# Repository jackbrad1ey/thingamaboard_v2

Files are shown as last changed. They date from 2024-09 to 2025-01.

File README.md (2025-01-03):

# Thingamaboard V2
This is the second iteration of my custom mechanical keyboard, a low-profile board aiming to be reliable, portable and fully-featured.

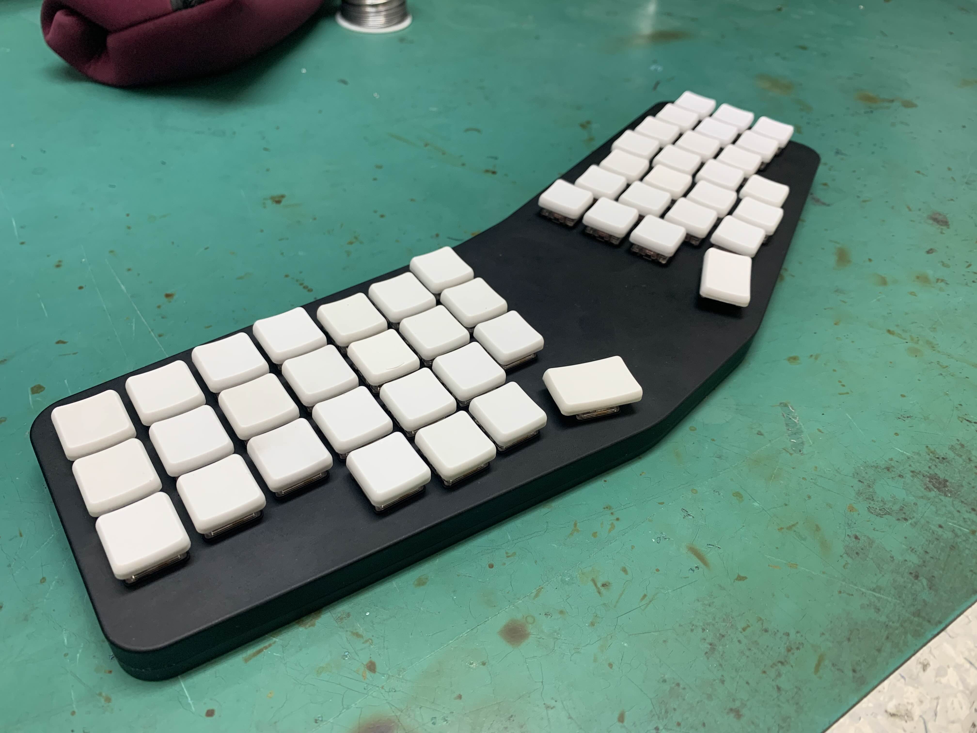
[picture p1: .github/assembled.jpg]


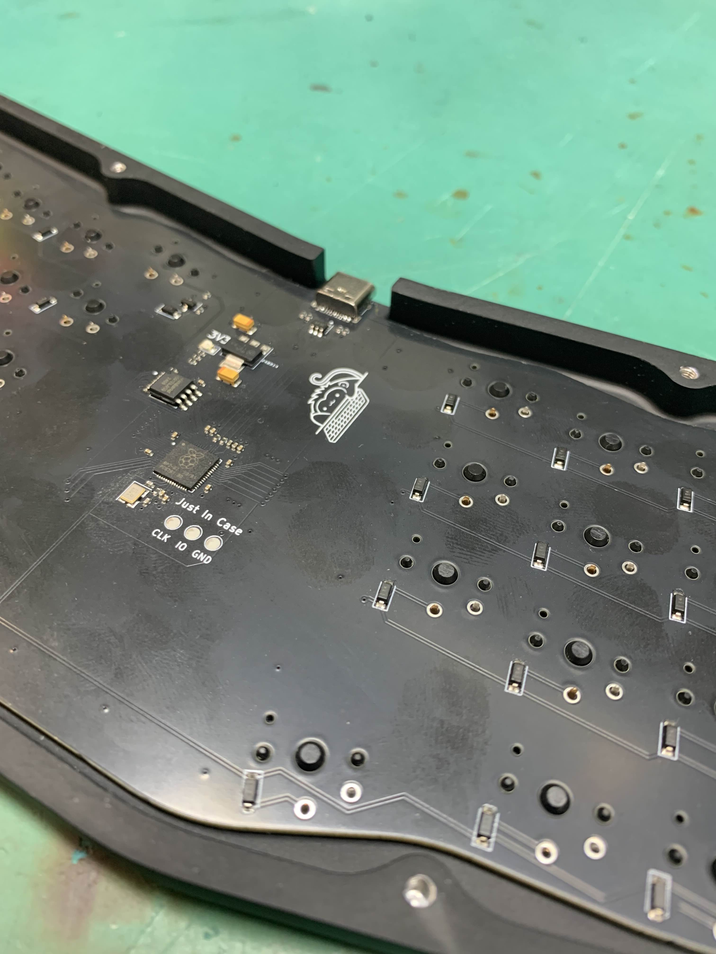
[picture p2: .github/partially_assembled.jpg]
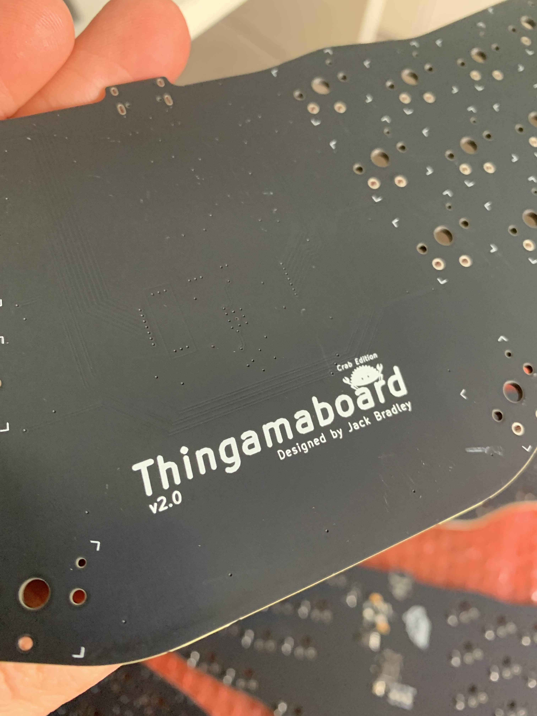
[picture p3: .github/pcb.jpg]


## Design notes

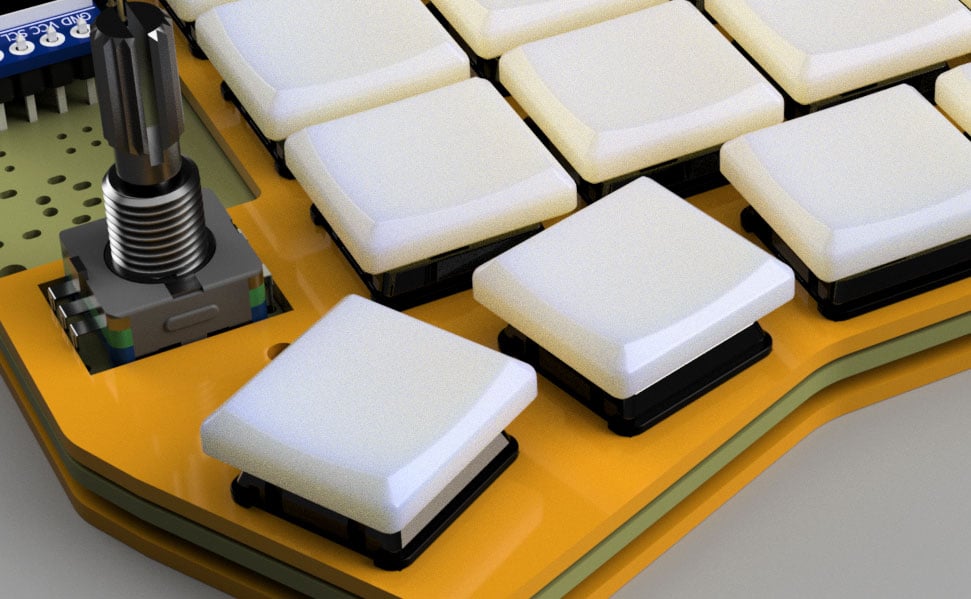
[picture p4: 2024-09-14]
CAD/keycaps/images/MBK-Keycap-render.jpg

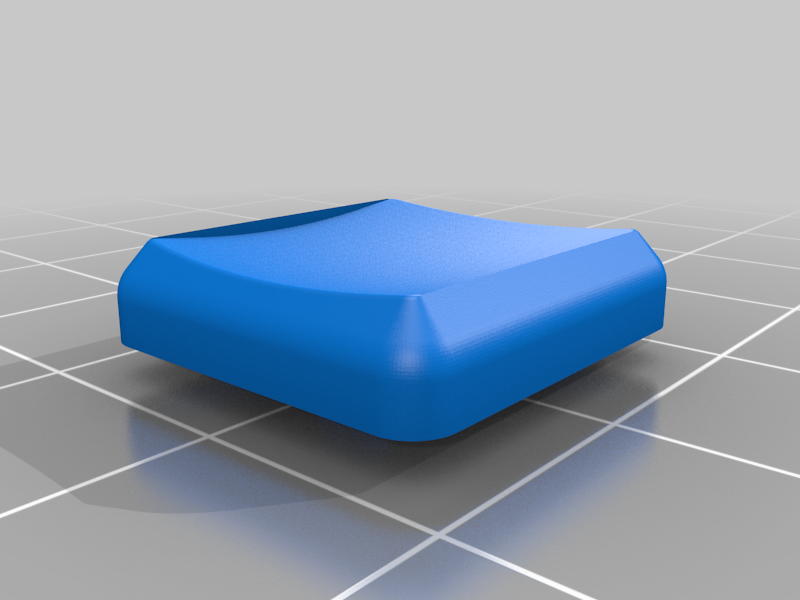
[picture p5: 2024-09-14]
CAD/keycaps/images/MBK_Keycap_-_1u_homing.png

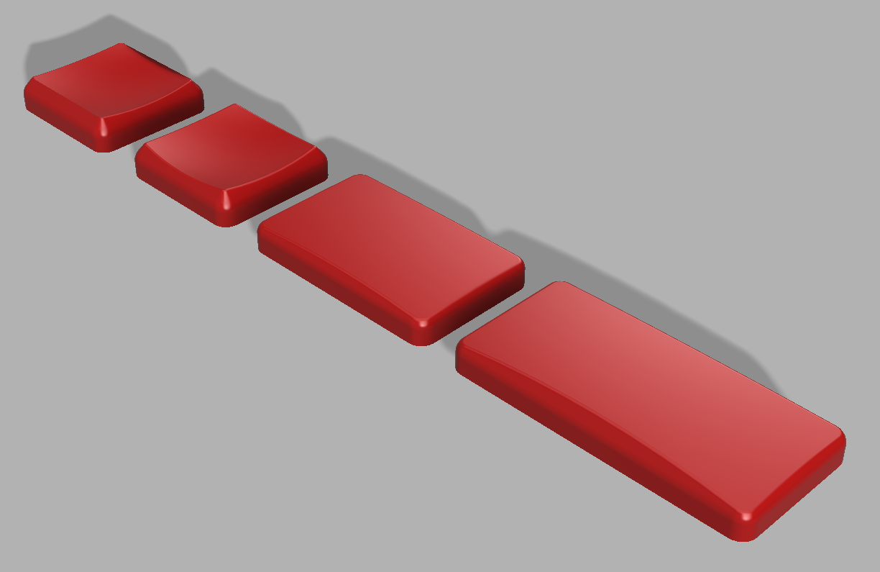
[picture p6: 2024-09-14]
CAD/keycaps/images/MBK_Keycap_family.png

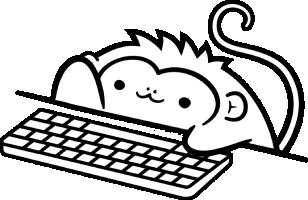
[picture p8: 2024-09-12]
pcb/graphics/monkei.png

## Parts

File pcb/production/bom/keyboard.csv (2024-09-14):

Comment | Designator | Footprint | JLCPCB Part #
10u Polarized capacitor | C1,C16 | C_1206_3216Metric | C7171
100n Unpolarized capacitor | C2,C5,C6,C7,C10,C11,C12,C13,C14,C15 | C_0402_1005Metric | C1525
15p Unpolarized capacitor | C3,C4 | C_0402_1005Metric | C1548
1u Unpolarized capacitor | C8,C9 | C_0402_1005Metric | C52923
NCD0805 Light emitting diode | D1 | LED_0805_2012Metric_Pad1.15x1.40mm_HandSolder | C84256
D_Small Diode, small symbol | D2,D3,D4,D5,D6,D7,D8,D9,D10,D11,D12,D13,D14,D15,D16,D17,D18,D19,D20,D21,D22,D23,D24,D25,D26,D27,D28,D29,D30,D31,D32,D33,D34,D35,D36,D37,D38,D39,D40,D41,D42,D43,D44,D45,D46,D47,D48,D49,D50,D51 | D_SOD-123 | C2099
USB_C_Receptacle_USB2.0 USB 2.0-only Type-C Receptacle connector | J1 | TYPE-C-31-M-12 | C165948
S8550 0.1A Ic, 30V Vce, PNP Transistor, SOT-23 | Q1 | SOT-23 | C105432
27 Resistor | R1,R2,R3,R12,R13 | R_0402_1005Metric | C25100
10k Resistor | R4,R5,R6,R7,R8,R10 | R_0402_1005Metric | C25744
1k Resistor | R9,R11 | R_0402_1005Metric | C11702
TestPoint test point | TP1,TP2,TP3 | TestPoint_Pad_D2.0mm
NCP1117-3.3_SOT223 1A Low drop-out regulator, Fixed Output 3.3V, SOT-223 | U1 | SOT-223-3_TabPin2 | C26537
USBLC6-2SC6 Very low capacitance ESD protection diode, 2 data-line, SOT-23-6 | U2 | SOT-23-6 | C2827654
W25Q128JVS 128Mb Serial Flash Memory, Standard/Dual/Quad SPI, SOIC-8 | U3 | SOIC-8_5.23x5.23mm_P1.27mm | C97521
RP2040 A microcontroller by Raspberry Pi | U4 | QFN-56-1EP_7x7mm_P0.4mm_EP3.2x3.2mm | C2040
ABM8-272_T3 Four pin crystal, GND on pins 2 and 4 | Y1 | Crystal_SMD_3225-4Pin_3.2x2.5mm | C20625731

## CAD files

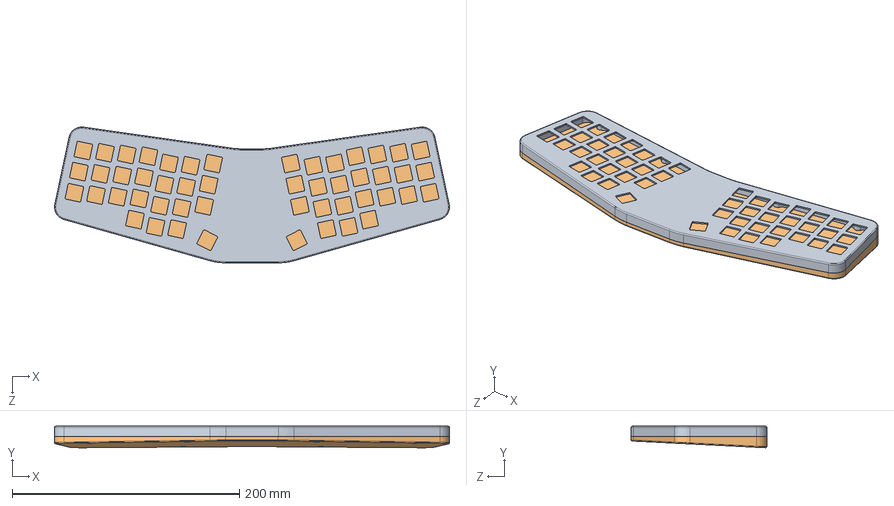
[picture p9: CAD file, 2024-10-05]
CAD/keyboard_assembly_2.SLDASM
347.3 x 18.9 x 119.5 mm
case_bottom_v2
top_case_v3

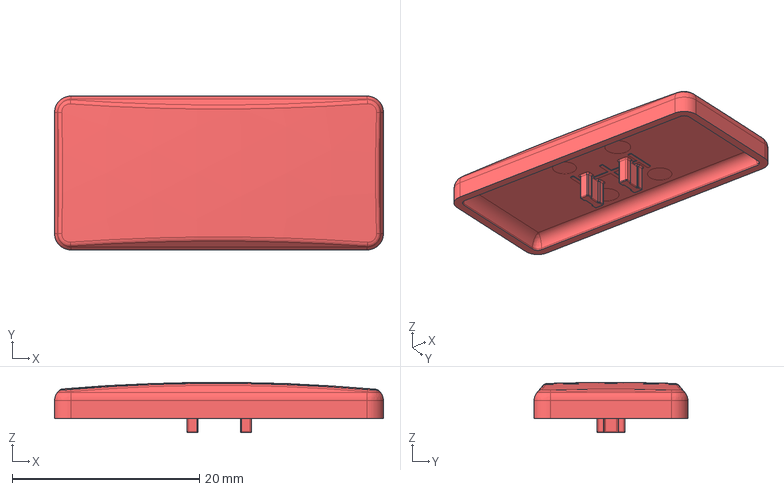
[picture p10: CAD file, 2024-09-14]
CAD/keycaps/files/MBK_Keycap_-_2u.step
35.2 x 16.4 x 5.38 mm

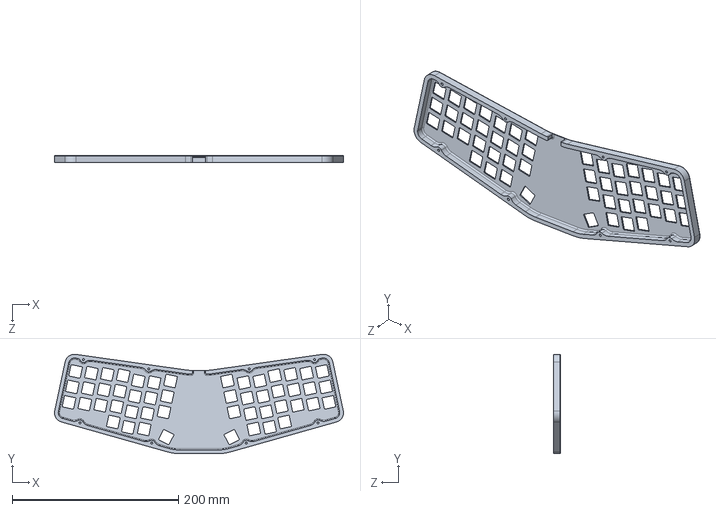
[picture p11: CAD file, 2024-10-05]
CAD/outputs/top_case.STEP
347.3 x 119.5 x 9.00 mm

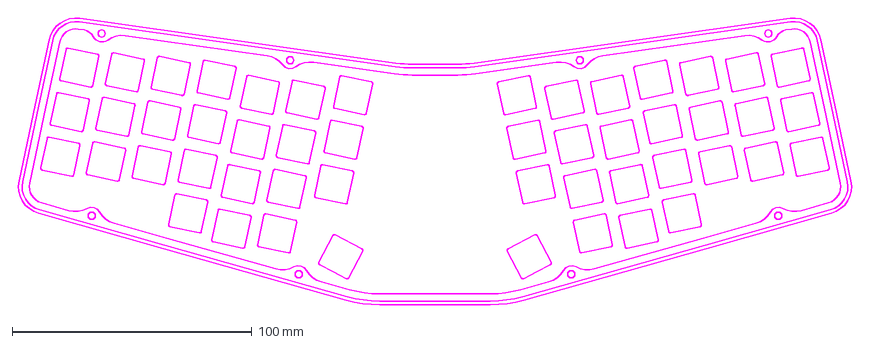
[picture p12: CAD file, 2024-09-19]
layout/plate_shape.dxf
349.3 x 120.2 mm

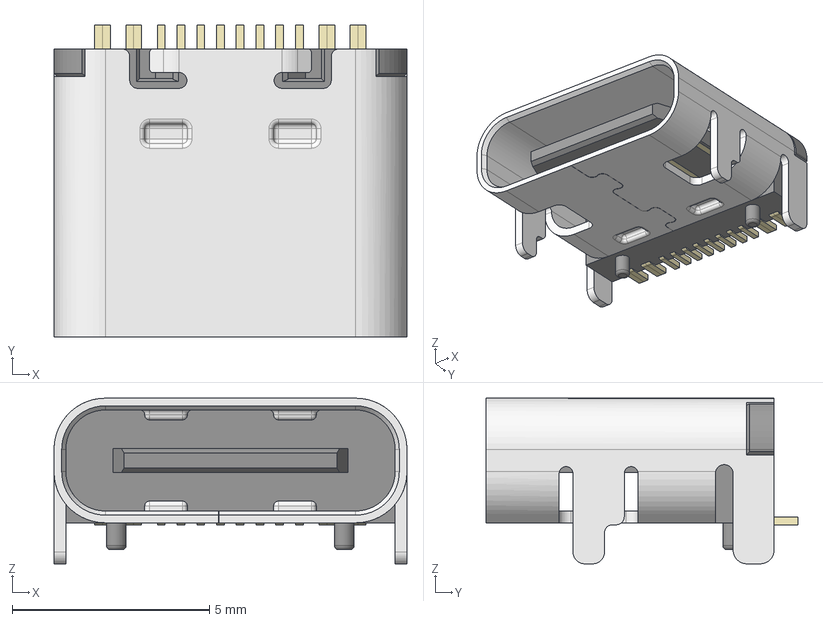
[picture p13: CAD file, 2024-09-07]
pcb/models/usb_c_connector.step
8.95 x 7.90 x 4.20 mm

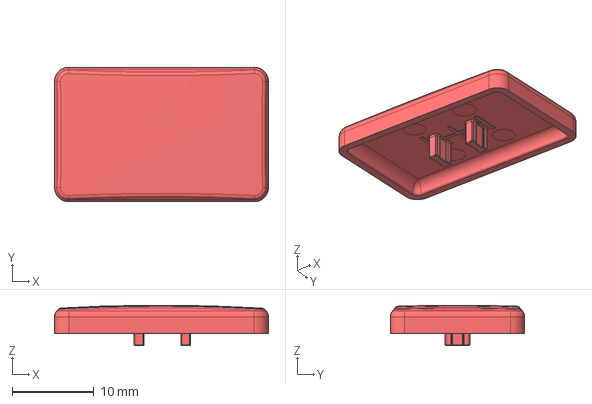
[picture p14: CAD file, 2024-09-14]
CAD/keycaps/files/MBK_Keycap_-_1.5u.step
26.2 x 16.4 x 4.94 mm

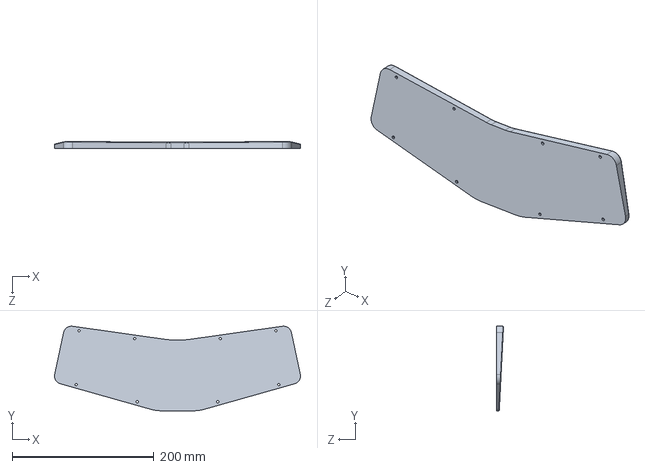
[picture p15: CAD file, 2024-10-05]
CAD/outputs/case_bottom.STEP
347.3 x 119.5 x 9.95 mm

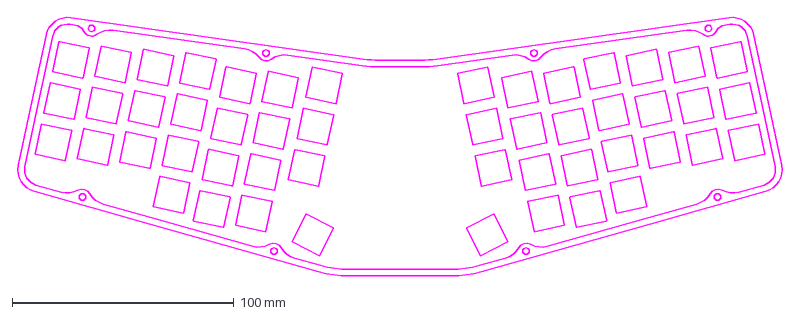
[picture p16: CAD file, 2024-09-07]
layout/case_outlines.dxf
346.1 x 117.1 mm

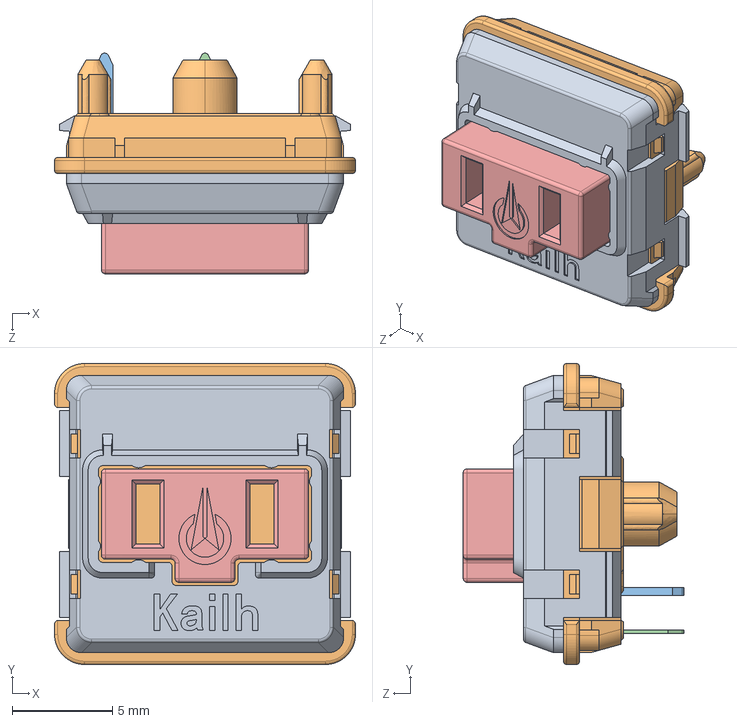
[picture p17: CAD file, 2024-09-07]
pcb/models/kailh_choc_switch.STEP
15.0 x 15.0 x 11.0 mm

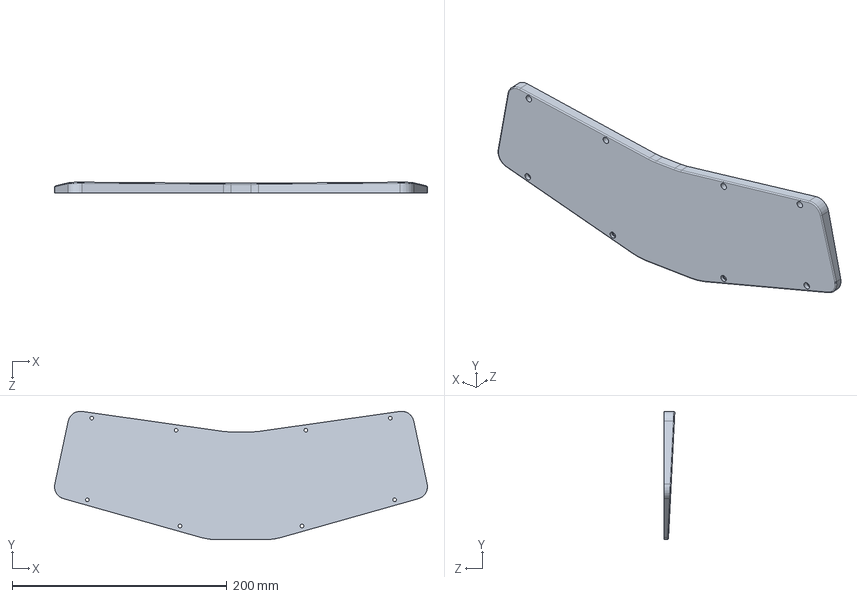
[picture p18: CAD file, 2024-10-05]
CAD/case_bottom_v2.SLDPRT
347.3 x 119.4 x 9.95 mm

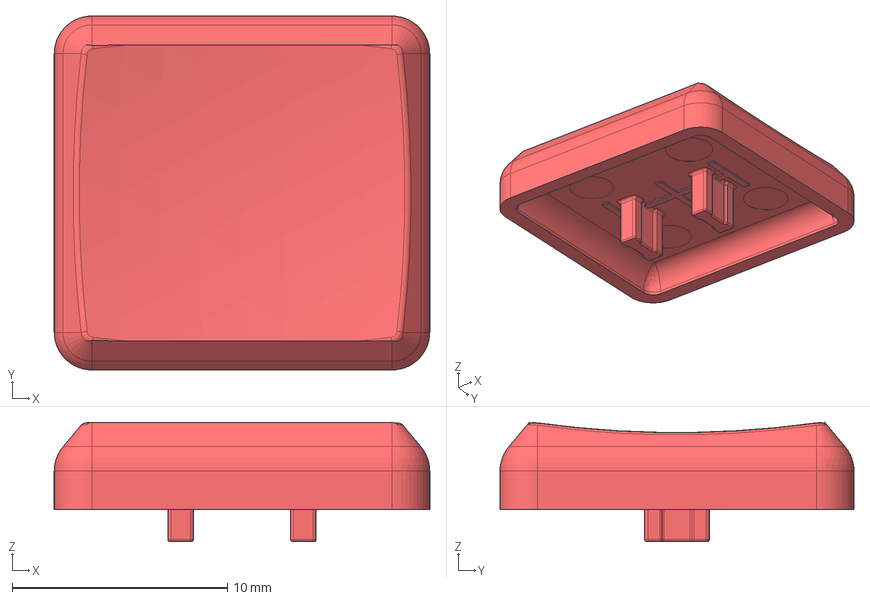
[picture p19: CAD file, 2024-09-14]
CAD/keycaps/files/MBK_Keycap_-_1u_Homing.step
17.5 x 16.4 x 5.54 mm

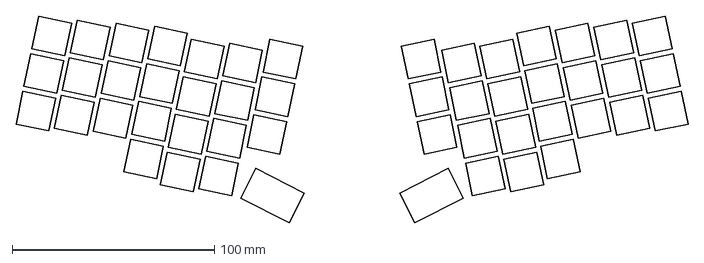
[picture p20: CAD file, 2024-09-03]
layout/key_layout.dxf
331.9 x 102.1 mm

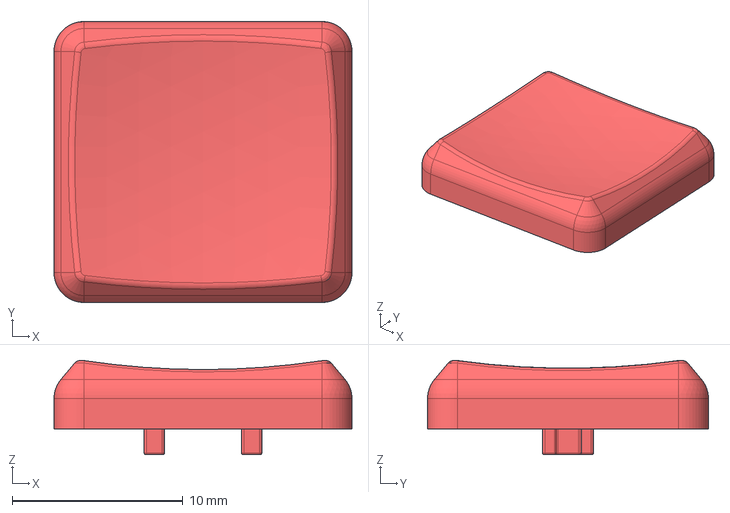
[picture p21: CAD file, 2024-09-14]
CAD/keycaps/files/MBK_Keycap_-_1u.step
17.4 x 16.4 x 5.52 mm

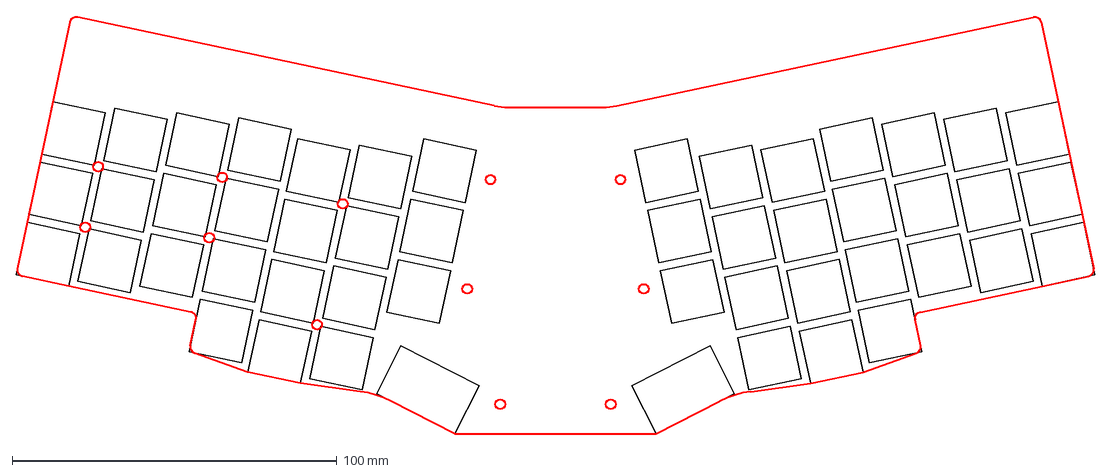
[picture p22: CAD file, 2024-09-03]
layout/pcb_layout.dxf
331.9 x 128.4 mm

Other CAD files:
CAD/keyboard.SLDASM
CAD/top_case_v3.SLDPRT
CAD/1U-keycap.SLDPRT
CAD/M3_bolt_10mm.SLDPRT
CAD/case_bottom.SLDPRT
CAD/keyboard_assembly.SLDDRW
CAD/keycaps/files/MBK_Keycap_-_1.5u.stl
CAD/keycaps/files/MBK_Keycap_-_1u.stl
CAD/keycaps/files/MBK_Keycap_-_1u_homing.stl
CAD/keycaps/files/MBK_Keycap_-_2u.stl
CAD/top_case.SLDPRT
CAD/top_case_v2.SLDPRT
CAD/top_case_v3.SLDDRW
layout/pcb_layout.dwg
layout/plate_shape.dwg

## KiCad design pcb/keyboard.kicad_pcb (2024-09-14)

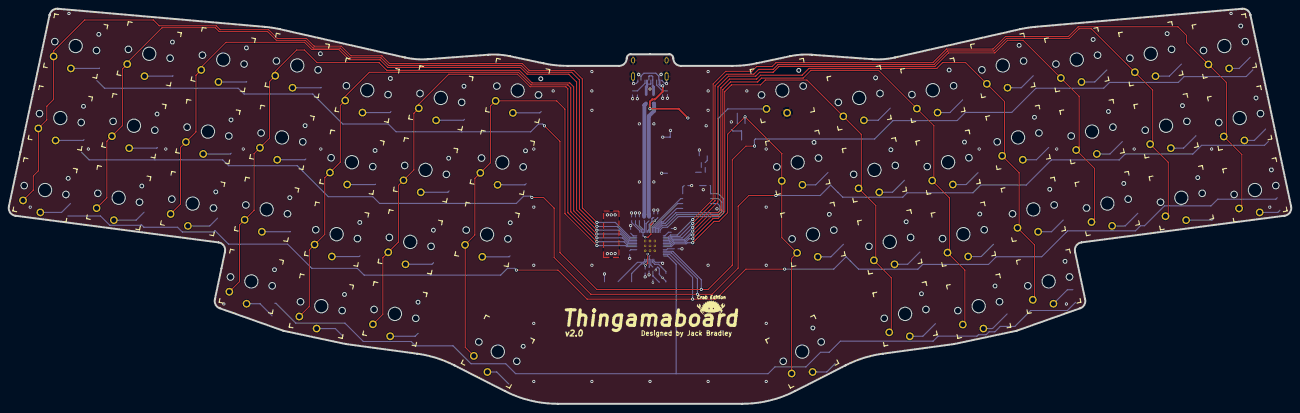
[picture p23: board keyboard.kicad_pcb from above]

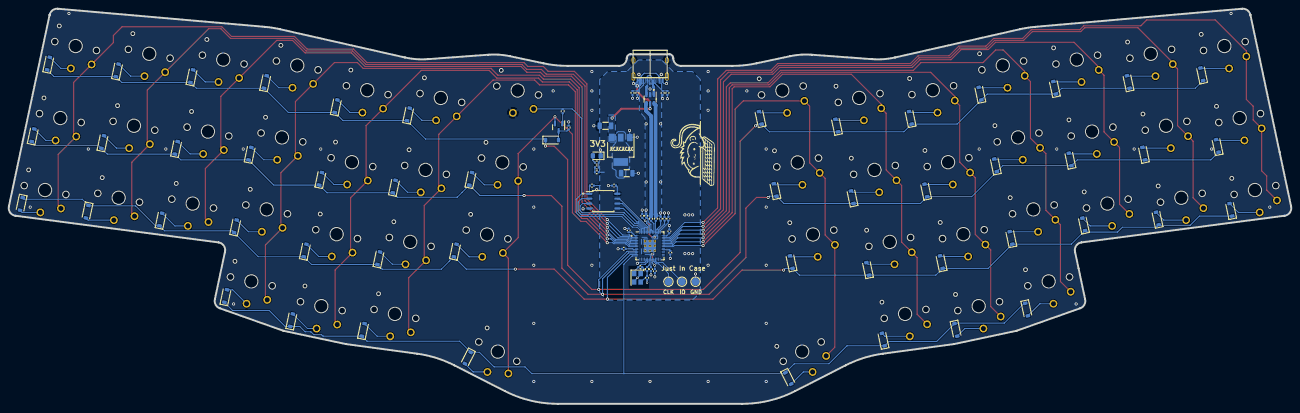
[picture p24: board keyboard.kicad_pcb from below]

Board: 2 copper layers, 331.1 x 102.0 mm, 140 parts (90 on the bottom side), 95 nets.

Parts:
C1, C16: 10u; C_1206_3216Metric
C2, C5, C6, C7, C10, C11, C12, C13, C14, C15: 100n; C_0402_1005Metric
C3, C4: 15p; C_0402_1005Metric
C8, C9: 1u; C_0402_1005Metric
D1: NCD0805; LED_0805_2012Metric_Pad1.15x1.40mm_HandSolder
D2, D3, D4, D5, D6, D7, D8, D9, D10, D11, D12, D13, D14, D15, D16, D17, D18, D19, D20, D21, D22, D23, D24, D25, D26, D27, D28, D29, D30, D31, D32, D33, D34, D35, D36, D37, D38, D39, D40, D41, D42, D43, D44, D45, D46, D47, D48, D49, D50, D51: D_Small; D_SOD-123
J1: USB_C_Receptacle_USB2.0; TYPE-C-31-M-12
Q1: S8550; SOT-23
R1, R2, R3, R12, R13: 27; R_0402_1005Metric
R4, R5, R6, R7, R8, R10: 10k; R_0402_1005Metric
R9, R11: 1k; R_0402_1005Metric
SW1, SW2, SW3, SW4, SW5, SW6, SW7, SW8, SW9, SW10, SW11, SW12, SW13, SW14, SW15, SW16, SW17, SW18, SW19, SW20, SW21, SW22, SW23, SW24, SW25, SW26, SW27, SW28, SW29, SW30, SW31, SW32, SW33, SW34, SW35, SW36, SW37, SW38, SW39, SW40, SW41, SW42, SW43, SW44, SW45, SW46, SW47, SW48, SW49, SW50: SW_Push; SW_PG1350
TP1, TP2, TP3: TestPoint; TestPoint_Pad_D2.0mm
U1: NCP1117-3.3_SOT223; SOT-223-3_TabPin2
U2: USBLC6-2SC6; SOT-23-6
U3: W25Q128JVS; SOIC-8_5.23x5.23mm_P1.27mm
U4: RP2040; QFN-56-1EP_7x7mm_P0.4mm_EP3.2x3.2mm
Y1: ABM8-272_T3; Crystal_SMD_3225-4Pin_3.2x2.5mm

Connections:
+1V1: C2.1, C6.1, C8.1, U4.23 (DVDD), U4.45 (VREG_VOUT), U4.50 (DVDD)
+3V3: C5.1, C7.1, C9.1, C10.1, C11.1, C12.1, C13.1, C14.1, C15.1, C16.1, R1.1, R8.1, U1.2 (VO), U3.8 (VCC), U4.1 (IOVDD), U4.10 (IOVDD), U4.22 (IOVDD), U4.26 (RUN), U4.33 (IOVDD), U4.42 (IOVDD), U4.43 (ADC_AVDD), U4.44 (VREG_IN), U4.48 (USB_VDD), U4.49 (IOVDD)
/MCU/BOOT: R8.2, R9.1, SW1.2, U3.1 (~CS), U4.56 (QSPI_SS)
/MCU/QSPI_SCLK: U3.6 (CLK), U4.52 (QSPI_SCLK)
/MCU/QSPI_SD0: U3.5 (DI(IO0)), U4.53 (QSPI_SD0)
/MCU/QSPI_SD1: U3.2 (DO(IO1)), U4.55 (QSPI_SD1)
/MCU/QSPI_SD2: U3.3 (IO2), U4.54 (QSPI_SD2)
/MCU/QSPI_SD3: U3.7 (IO3), U4.51 (QSPI_SD3)
/MCU/SWCLK: TP2.1, U4.24 (SWCLK)
/MCU/SWDIO: TP1.1, U4.25 (SWD)
/MCU/USB_D+: R12.1, U2.4 (I/O2)
/MCU/USB_D-: R13.1, U2.6 (I/O1)
/MCU/XIN: C3.1, U4.20 (XIN), Y1.1
/MCU/XOUT: R11.2, U4.21 (XOUT)
/MCU/col0: SW2.2, SW3.2, SW4.2, U4.41 (GPIO29_ADC3)
/MCU/col1: SW5.2, SW6.2, SW7.2, U4.40 (GPIO28_ADC2)
/MCU/col2: SW8.2, SW9.2, SW10.2, U4.39 (GPIO27_ADC1)
/MCU/col3: SW11.2, SW12.2, SW13.2, SW14.2, U4.38 (GPIO26_ADC0)
/MCU/col4: SW15.2, SW16.2, SW17.2, SW18.2, U4.37 (GPIO25)
/MCU/col5: SW19.2, SW20.2, SW21.2, SW22.2, U4.36 (GPIO24)
/MCU/col6: SW23.2, SW24.2, SW25.2, SW26.2, U4.35 (GPIO23)
/MCU/col7: Q1.2 (E), SW27.2, SW28.2, SW29.2, U4.8 (GPIO6)
/MCU/col8: SW30.2, SW31.2, SW32.2, SW33.2, U4.7 (GPIO5)
/MCU/col9: SW34.2, SW35.2, SW36.2, SW37.2, U4.6 (GPIO4)
/MCU/col10: SW38.2, SW39.2, SW40.2, SW41.2, U4.5 (GPIO3)
/MCU/col11: SW42.2, SW43.2, SW44.2, U4.4 (GPIO2)
/MCU/col12: SW45.2, SW46.2, SW47.2, U4.3 (GPIO1)
/MCU/col13: SW48.2, SW49.2, SW50.2, U4.2 (GPIO0)
/MCU/row0: D2.1 (K), D5.1 (K), D8.1 (K), D11.1 (K), D15.1 (K), D19.1 (K), D23.1 (K), D27.1 (K), D31.1 (K), D35.1 (K), D39.1 (K), D43.1 (K), D46.1 (K), D49.1 (K), U4.11 (GPIO8)
/MCU/row1: D3.1 (K), D6.1 (K), D9.1 (K), D12.1 (K), D16.1 (K), D20.1 (K), D24.1 (K), D28.1 (K), D32.1 (K), D36.1 (K), D40.1 (K), D44.1 (K), D47.1 (K), D50.1 (K), U4.12 (GPIO9)
/MCU/row2: D4.1 (K), D7.1 (K), D10.1 (K), D13.1 (K), D17.1 (K), D21.1 (K), D25.1 (K), D29.1 (K), D33.1 (K), D37.1 (K), D41.1 (K), D45.1 (K), D48.1 (K), D51.1 (K), U4.13 (GPIO10)
/MCU/row3: D14.1 (K), D18.1 (K), D22.1 (K), D26.1 (K), D30.1 (K), D34.1 (K), D38.1 (K), D42.1 (K), U4.14 (GPIO11)
/connectors/CC1: J1.A5 (CC1), R6.1, R7.1
/connectors/CC2: J1.B5 (CC2), R4.1, R5.1
/inputs/SS_OUT: D27.2 (A), Q1.3 (C), R10.1
GND: C1.2, C2.2, C3.2, C4.2, C5.2, C6.2, C7.2, C8.2, C9.2, C10.2, C11.2, C12.2, C13.2, C14.2, C15.2, C16.2, D1.1 (K), J1.A1 (GND), J1.A12 (GND), J1.B1 (GND), J1.B12 (GND), J1.S1 (SHIELD), R4.2, R5.2, R6.2, R7.2, R10.2, SW1.1, TP3.1, U1.1 (GND), U2.2 (GND), U3.4 (GND), U4.19 (TESTEN), U4.57 (GND), Y1.2, Y1.4
unnamed: C4.1, R11.1, Y1.3
unnamed: D1.2 (A), R3.2
unnamed: D2.2 (A), SW2.1
unnamed: D3.2 (A), SW3.1
unnamed: D4.2 (A), SW4.1
unnamed: D5.2 (A), SW5.1
unnamed: D6.2 (A), SW6.1
unnamed: D7.2 (A), SW7.1
unnamed: D8.2 (A), SW8.1
unnamed: D9.2 (A), SW9.1
unnamed: D10.2 (A), SW10.1
unnamed: D11.2 (A), SW11.1
unnamed: D12.2 (A), SW12.1
unnamed: D13.2 (A), SW13.1
unnamed: D14.2 (A), SW14.1
unnamed: D15.2 (A), SW15.1
unnamed: D16.2 (A), SW16.1
unnamed: D17.2 (A), SW17.1
unnamed: D18.2 (A), SW18.1
unnamed: D19.2 (A), SW19.1
unnamed: D20.2 (A), SW20.1
unnamed: D21.2 (A), SW21.1
unnamed: D22.2 (A), SW22.1
unnamed: D23.2 (A), SW23.1
unnamed: D24.2 (A), SW24.1
unnamed: D25.2 (A), SW25.1
unnamed: D26.2 (A), SW26.1
unnamed: D28.2 (A), SW27.1
unnamed: D29.2 (A), SW28.1
unnamed: D30.2 (A), SW29.1
unnamed: D31.2 (A), SW30.1
unnamed: D32.2 (A), SW31.1
unnamed: D33.2 (A), SW32.1
unnamed: D34.2 (A), SW33.1
unnamed: D35.2 (A), SW34.1
unnamed: D36.2 (A), SW35.1
unnamed: D37.2 (A), SW36.1
unnamed: D38.2 (A), SW37.1
unnamed: D39.2 (A), SW38.1
unnamed: D40.2 (A), SW39.1
unnamed: D41.2 (A), SW40.1
unnamed: D42.2 (A), SW41.1
unnamed: D43.2 (A), SW42.1
unnamed: D44.2 (A), SW43.1
unnamed: D45.2 (A), SW44.1
unnamed: D46.2 (A), SW45.1
unnamed: D47.2 (A), SW46.1
unnamed: D48.2 (A), SW47.1
unnamed: D49.2 (A), SW48.1
unnamed: D50.2 (A), SW49.1
unnamed: D51.2 (A), SW50.1
unnamed: J1.A6 (D+), J1.B6 (D+), U2.3 (I/O2)
unnamed: J1.A7 (D-), J1.B7 (D-), U2.1 (I/O1)
unnamed: Q1.1 (B), R9.2
unnamed: R1.2, R2.1
unnamed: R2.2, R3.1
unnamed: R13.2, U4.46 (USB_DM)
unnamed: R12.2, U4.47 (USB_DP)
VBUS: C1.1, J1.A4 (VBUS), J1.A9 (VBUS), J1.B4 (VBUS), J1.B9 (VBUS), U1.3 (VI), U2.5 (VBUS)

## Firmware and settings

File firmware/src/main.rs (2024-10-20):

#![no_std]
#![no_main]

mod key_codes;
mod key_layers;
mod key_scan;

use defmt::*;
use key_codes::KeyCode;
use core::borrow::BorrowMut;
use core::iter::Empty;
use core::sync::atomic::{AtomicBool, Ordering};

use embassy_executor::Spawner;
use embassy_rp::gpio::{Level, Input, Output, Pull};
use embassy_rp::bind_interrupts;
use embassy_rp::peripherals::USB;
use embassy_rp::usb::{Driver, InterruptHandler};
use embassy_usb::class::hid::{HidReaderWriter, ReportId, RequestHandler, State};
use embassy_usb::control::OutResponse;
use embassy_usb::{Builder, Config, Handler};
use embassy_time::{Duration, Timer};
use embassy_futures::join::join;

use usbd_hid::descriptor::{KeyboardReport, SerializedDescriptor};

use {defmt_rtt as _, panic_probe as _};


const NUM_COLS: usize = 14;
const NUM_ROWS: usize = 4;
const KEYS_PER_REPORT: usize = 6;

bind_interrupts!(struct Irqs {
    USBCTRL_IRQ => InterruptHandler<USB>;
});

#[embassy_executor::main]
async fn main(_spawner: Spawner) {
    let rp = embassy_rp::init(Default::default());
    // Create the driver, from the HAL.
    let driver = Driver::new(rp.USB, Irqs);

    // Create embassy-usb Config
    let mut config = Config::new(0xc0de, 0xcafe);
    config.manufacturer = Some("Jack Bradley");
    config.product = Some("Thingamaboard V2");
    config.serial_number = Some("000001");
    config.max_power = 100;
    config.max_packet_size_0 = 64;

        // Create embassy-usb DeviceBuilder using the driver and config.
    // It needs some buffers for building the descriptors.
    let mut config_descriptor = [0; 256];
    let mut bos_descriptor = [0; 256];
    // You can also add a Microsoft OS descriptor.
    let mut msos_descriptor = [0; 256];
    let mut control_buf = [0; 64];

    let mut request_handler = MyRequestHandler {};
    let mut device_handler = MyDeviceHandler::new();

    let mut state = State::new();

    let mut builder = Builder::new(
        driver,
        config,
        &mut config_descriptor,
        &mut bos_descriptor,
        &mut msos_descriptor,
        &mut control_buf,
    );

    // builder.handler(&mut device_handler);


    let config = embassy_usb::class::hid::Config {
        report_descriptor: KeyboardReport::desc(),
        request_handler: None,
        poll_ms: 60,
        max_packet_size: 64,
    };
    let hid = HidReaderWriter::<_, 1, 8>::new(&mut builder, &mut state, config);


    // Build and run the USB device
    let mut usb = builder.build();
    let usb_fut = usb.run();

    let (reader, mut writer) = hid.split();

    let mut modifier_byte = 0;
    let mut keycodes: [u8; KEYS_PER_REPORT] = [0; KEYS_PER_REPORT];

    let mut columns: [Output; NUM_COLS] = [
        Output::new(rp.PIN_29,Level::Low),
        Output::new(rp.PIN_28,Level::Low),
        Output::new(rp.PIN_27,Level::Low),
        Output::new(rp.PIN_26,Level::Low),
        Output::new(rp.PIN_25,Level::Low),
        Output::new(rp.PIN_24,Level::Low),
        Output::new(rp.PIN_23,Level::Low),
        Output::new(rp.PIN_6,Level::Low),
        Output::new(rp.PIN_5,Level::Low),
        Output::new(rp.PIN_4,Level::Low),
        Output::new(rp.PIN_3,Level::Low),
        Output::new(rp.PIN_2,Level::Low),
        Output::new(rp.PIN_1,Level::Low),
        Output::new(rp.PIN_0,Level::Low)
    ];

    let mut rows: [Input; NUM_ROWS] = [
        Input::new(rp.PIN_8, Pull::Down),
        Input::new(rp.PIN_9, Pull::Down),
        Input::new(rp.PIN_10, Pull::Down),
        Input::new(rp.PIN_11, Pull::Down)
    ];

    for i in 0..NUM_ROWS {
        rows[i].set_schmitt(true);
    }


    let mut prev_report = KeyboardReport {
        keycodes: keycodes,
        leds: 0,
        modifier: 0,
        reserved: 0
    };

    
    let main_loop = async {
        loop {
            keycodes = [0; KEYS_PER_REPORT];
            modifier_byte = 0;

            key_scan::scan_for_keys(&mut keycodes, &mut modifier_byte, &mut columns, &mut rows).await;
            let report = KeyboardReport {
                keycodes: keycodes,
                leds: 0,
                modifier: modifier_byte,
                reserved: 0,
            };

            if report != prev_report {
                match writer.write_serialize(&report).await {
                    Ok(()) => {}
                    Err(e) => warn!("Failed to send report: {:?}", e),
                };

                prev_report = report;
            }

            Timer::after_micros(1000).await;
        }
    };


    let out_fut = async {
        reader.run(false, &mut request_handler).await;
    };

    // Run everything concurrently.
    // If we had made everything `'static` above instead, we could do this using separate tasks instead.
    join(usb_fut, join(main_loop, out_fut)).await;
}

struct MyRequestHandler {}

impl RequestHandler for MyRequestHandler {
    fn get_report(&mut self, id: ReportId, _buf: &mut [u8]) -> Option<usize> {
        info!("Get report for {:?}", id);
        None
    }

    fn set_report(&mut self, id: ReportId, data: &[u8]) -> OutResponse {
        info!("Set report for {:?}: {=[u8]}", id, data);
        OutResponse::Accepted
    }

    fn set_idle_ms(&mut self, id: Option<ReportId>, dur: u32) {
        info!("Set idle rate for {:?} to {:?}", id, dur);
    }

    fn get_idle_ms(&mut self, id: Option<ReportId>) -> Option<u32> {
        info!("Get idle rate for {:?}", id);
        None
    }
}

struct MyDeviceHandler {
    configured: AtomicBool,
}

impl MyDeviceHandler {
    fn new() -> Self {
        MyDeviceHandler {
            configured: AtomicBool::new(false),
        }
    }
}

impl Handler for MyDeviceHandler {
    fn enabled(&mut self, enabled: bool) {
        self.configured.store(false, Ordering::Relaxed);
        if enabled {
            info!("Device enabled");
        } else {
            info!("Device disabled");
        }
    }

    fn reset(&mut self) {
        self.configured.store(false, Ordering::Relaxed);
        info!("Bus reset, the Vbus current limit is 100mA");
    }

    fn addressed(&mut self, addr: u8) {
        self.configured.store(false, Ordering::Relaxed);
        info!("USB address set to: {}", addr);
    }

    fn configured(&mut self, configured: bool) {
        self.configured.store(configured, Ordering::Relaxed);
        if configured {
            info!("Device configured, it may now draw up to the configured current limit from Vbus.")
        } else {
            info!("Device is no longer configured, the Vbus current limit is 100mA.");
        }
    }
}

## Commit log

2024-09-03 Lot's of work has been done
    [connectors.kicad_sch, inputs.kicad_sch, key_layout.dxf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]
2024-09-04 Preliminary layout done
    [pcb_layout.dwg]
2024-09-06 Haven't backed up in a bit
    [inputs.kicad_sch, keyboard.kicad_pcb, pcb_layout.dwg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]
2024-09-07 Preliminary case design done, moving on to PCB design
    [case_bottom.SLDPRT, case_bottom.STEP, case_outlines.dxf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]
2024-09-07 PCB work in progress
    [MCU.kicad_sch, keyboard.kicad_sch, power.kicad_sch]
2024-09-07 Schematic done, starting PCB design
    [MCU.kicad_sch, connectors.kicad_sch, inputs.kicad_sch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]
2024-09-07 Switches placement done, updated footprints to include model
    [MCU.kicad_sch, inputs.kicad_sch, kailh_choc_switch.STEP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]
2024-09-07 Starting diode placement
    [keyboard.kicad_pcb]
2024-09-07 Diode placement done
    [keyboard.kicad_pcb]
2024-09-07 Routing in progress
    [MCU.kicad_sch, inputs.kicad_sch, keyboard.kicad_pcb]
2024-09-08 More routing progress
    [MCU.kicad_sch, keyboard.kicad_pcb]
2024-09-08 Further progress on routing
    [MCU.kicad_sch, keyboard.kicad_pcb]
2024-09-08 More routing yippieeeee
    [MCU.kicad_sch, keyboard.kicad_pcb]
2024-09-09 Preliminary routing done
    [keyboard.kicad_pcb]
2024-09-09 PCB updates, cad updates
    [case_bottom.SLDPRT, keyboard.SLDASM, keyboard.kicad_pcb]
2024-09-11 Ready to produce test production files before updating some components
    [keyboard-B_Cu.gbr, keyboard-B_Mask.gbr, keyboard-B_Paste.gbr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]
2024-09-11 Rerouted a lot of stuff
    [MCU.kicad_sch, connectors.kicad_sch, inputs.kicad_sch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]
2024-09-11 Further updates to routing
    [keyboard.kicad_pcb]
2024-09-12 PCB design complete
    [MCU.kicad_sch, connectors.kicad_sch, inputs.kicad_sch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]
2024-09-13 Touched up PCB slightly
    [keyboard.kicad_pcb]
2024-09-14 PCB ready for production
    [MCU.kicad_sch, case_bottom.SLDPRT, case_bottom.STEP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]
2024-09-14 Updated assembly a little
    [MBK_Keycap_-_1.5u.step, MBK_Keycap_-_1.5u.stl, MBK_Keycap_-_1u.step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]
2024-09-15 Updates to the CAD
    [1U-keycap.SLDPRT]
2024-09-18 Updated case outline for countersunk bolts
    [plate_shape.dwg]
2024-09-19 Working on the new keyboard CAD
    [case_bottom_v2.SLDPRT, plate_shape.dwg, plate_shape.dxf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]
2024-09-24 Starting some work on the code
    [M3_bolt_10mm.SLDPRT, case_bottom_v2.SLDPRT, case_bottom_v2.STEP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]
2024-10-05 CAD ready for JLC review
    [case_bottom.STEP, case_bottom_v2.SLDPRT, case_bottom_v2.STEP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]
